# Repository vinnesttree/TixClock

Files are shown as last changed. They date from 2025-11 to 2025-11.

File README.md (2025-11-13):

# **TixClock**

The Tix Clock was originally sold in 2006 by ThinkGeek. Unfortunately, these are no longer sold. This project hopes to try to recreate this iconic clock in a miniature format.

# **TODO**
There are still things to do with this project which includes

 - Battery Management is not working
 - Encloser is not designed or tested

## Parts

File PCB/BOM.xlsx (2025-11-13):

Id | Designator | Footprint | Quantity | Designation | Supplier and ref | Column1 | _1
1 | R23,R8,R10 | R_0805_2012Metric | 3 | 1k
2 | U8 | SOIC-8-1EP_3.9x4.9mm_P1.27mm_EP2.41x3.81mm | 1 | TP4056-42-ESOP8
3 | U7 | Texas_RWU0007A_VQFN-7_2x2mm_P0.5mm | 1 | TPS61022
4 | U1 | QFN-56-1EP_7x7mm_P0.4mm_EP3.2x3.2mm | 1 | RP2040
5 | BT1 | BatteryHolder_Keystone_1042_1x18650 | 1 | Battery_Cell
6 | D31 | LED_0805_2012Metric | 1 | LED
7 | D27,D11,D24,D14,D13,D5,D10,D25,D18,D19,D15,D12,D9,D3,D6,D28,D7,D20,D2,D4,D23,D22,D17,D16,D8,D21,D26 | LED_WS2812B_PLCC4_5.0x5.0mm_P3.2mm | 27 | WS2812B
8 | U4 | SOT-23-5 | 1 | SN74LV1T34DBV
9 | R1,R2 | R_0805_2012Metric | 2 | 5.1k
10 | R3,R4 | R_0805_2012Metric | 2 | 27
11 | C9,C4,C3,C11,C2,C5 | C_0805_2012Metric | 6 | 10uF
12 | R14 | R_0805_2012Metric | 1 | 100k
13 | R21,R20 | R_0805_2012Metric | 2 | 4.7k
14 | U3 | SOIC-8_5.3x5.3mm_P1.27mm | 1 | W25Q32JVSS
15 | SW2,SW4,SW1,SW3 | SW_SPST_CK_RS282G05A3 | 4 | SW_SPST
16 | D1,D30,D29 | D_SMA | 3 | D_Schottky_Small
17 | R18,R19,R16,R17,R7,R15,R6 | R_0805_2012Metric | 7 | 10k
18 | R13 | R_0805_2012Metric | 1 | 732k
19 | U2 | SOT-223-3_TabPin2 | 1 | AMS1117-3.3
20 | C1,C10 | C_0805_2012Metric | 2 | 100nF
21 | R11 | R_0805_2012Metric | 1 | 1.2k
22 | R5,R9 | R_0805_2012Metric | 2 | 100
23 | Q1 | TSOP-6_1.65x3.05mm_P0.95mm | 1 | PMN48XP
24 | J2 | PinSocket_1x03_P2.54mm_Vertical | 1 | Conn_01x03
25 | C6,C7 | C_0805_2012Metric | 2 | 15pF
26 | R12 | R_0805_2012Metric | 1 | 0.4
27 | Y1 | Crystal_SMD_SeikoEpson_FA238-4Pin_3.2x2.5mm | 1 | 12MHz
28 | R22 | R_0805_2012Metric | 1 | 1M
29 | L1 | L_0805_2012Metric | 1 | 1uH
30 | U6 | SOT95P285X140-6N | 1 | 8205A
31 | BT2 | BatteryHolder_Keystone_3034_1x20mm | 1 | Battery_Cell
32 | U5 | SOT-23-6 | 1 | DW01A
33 | C8 | C_0805_2012Metric | 1 | 0.1uF
34 | U9 | SOIC-8_3.9x4.9mm_P1.27mm | 1 | PCF8523T
35 | J1 | USB_C_Receptacle_HRO_TYPE-C-31-M-12 | 1 | USB_C_Receptacle_USB2.0_16P

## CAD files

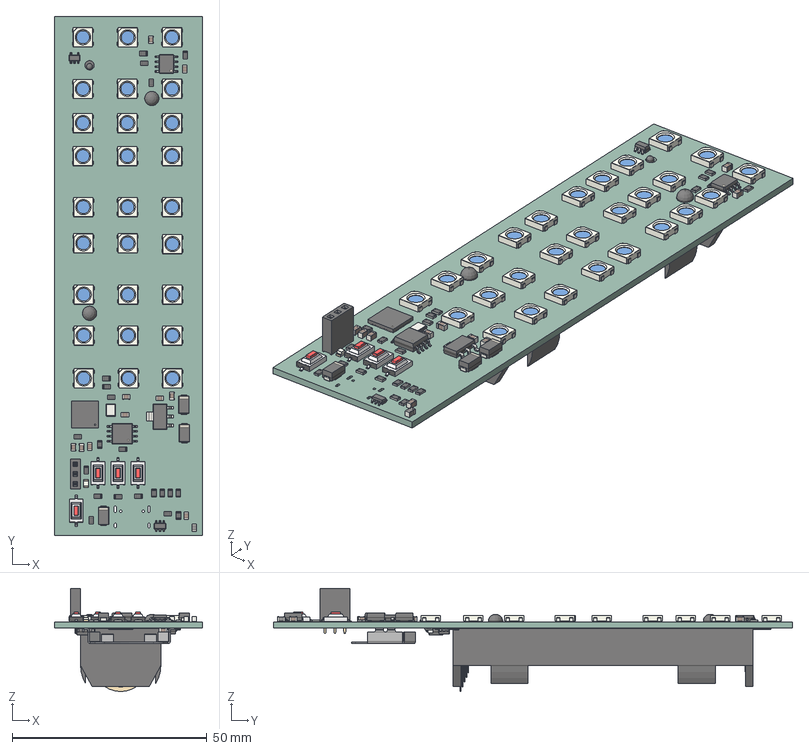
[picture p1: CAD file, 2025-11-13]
PCB/PCBProject.step
38.1 x 133.4 x 26.5 mm
LED_WS2812B_PLCC4_5.0x5.0mm_P3.2mm x 27
SOT-23-5
R_0805_2012Metric x 23
SOIC-8-1EP_3.9x4.9mm_P1.27mm_EP2.41x3.81mm
C_0805_2012Metric x 11
SOIC-8_5.3x5.3mm_P1.27mm
SW_SPST_CK_RS282G05A3 x 4
D_SMA x 3
SOT-223
LED_0805_2012Metric
TSOP-6_1.65x3.05mm_P0.95mm
QFN-56-1EP_7x7mm_P0.4mm_EP3.2x3.2mm
PinSocket_1x03_P2.54mm_Vertical
Crystal_SMD_SeikoEpson_FA238-4Pin_3.2x2.5mm
L_0805_2012Metric
BatteryHolder_Keystone_1042_1x18650
BatteryHolder_Keystone_3034_1x20mm
SOT-23-6
SOIC-8_3.9x4.9mm_P1.27mm
PCBProject_PCB

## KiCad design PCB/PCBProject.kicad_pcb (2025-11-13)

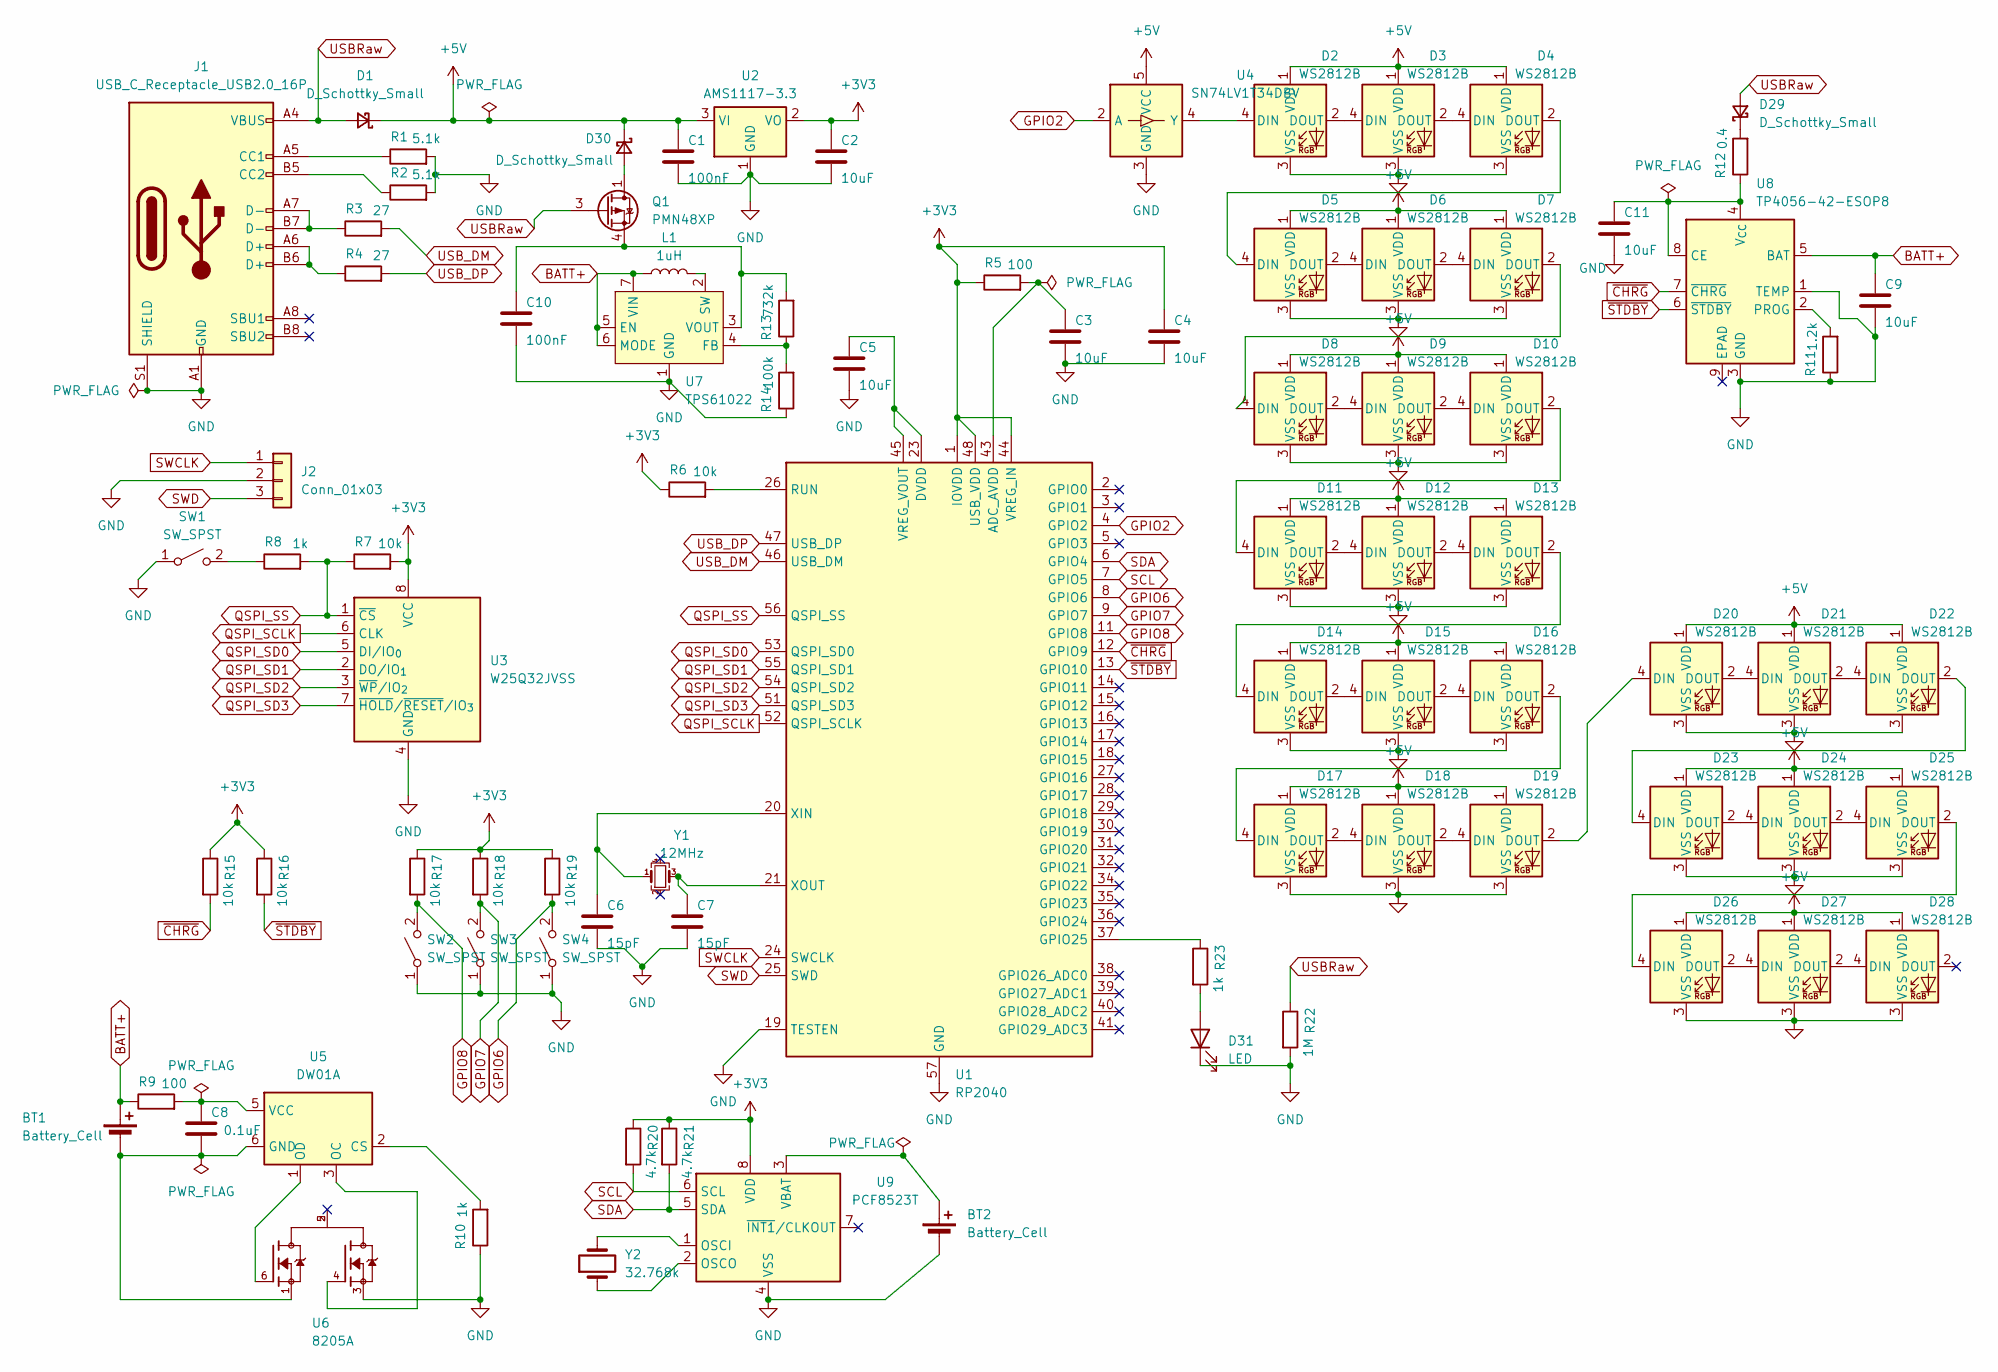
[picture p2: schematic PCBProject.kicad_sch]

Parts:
BT1: Battery_Cell; BatteryHolder_Keystone_1042_1x18650
BT2: Battery_Cell; BatteryHolder_Keystone_3034_1x20mm
C1, C10: 100nF; C_0805_2012Metric
C2, C3, C4, C5, C9, C11: 10uF; C_0805_2012Metric
C6, C7: 15pF; C_0805_2012Metric
C8: 0.1uF; C_0805_2012Metric
D1, D29, D30: D_Schottky_Small; D_SMA
D2, D3, D4, D5, D6, D7, D8, D9, D10, D11, D12, D13, D14, D15, D16, D17, D18, D19, D20, D21, D22, D23, D24, D25, D26, D27, D28: WS2812B; LED_WS2812B_PLCC4_5.0x5.0mm_P3.2mm
D31: LED; LED_0805_2012Metric
J1: USB_C_Receptacle_USB2.0_16P; USB_C_Receptacle_HRO_TYPE-C-31-M-12
J2: Conn_01x03; PinSocket_1x03_P2.54mm_Vertical
L1: 1uH; L_0805_2012Metric
Q1: PMN48XP; TSOP-6_1.65x3.05mm_P0.95mm
R1, R2: 5.1k; R_0805_2012Metric
R3, R4: 27; R_0805_2012Metric
R5, R9: 100; R_0805_2012Metric
R6, R7, R15, R16, R17, R18, R19: 10k; R_0805_2012Metric
R8, R10, R23: 1k; R_0805_2012Metric
R11: 1.2k; R_0805_2012Metric
R12: 0.4; R_0805_2012Metric
R13: 732k; R_0805_2012Metric
R14: 100k; R_0805_2012Metric
R20, R21: 4.7k; R_0805_2012Metric
R22: 1M; R_0805_2012Metric
SW1, SW2, SW3, SW4: SW_SPST; SW_SPST_CK_RS282G05A3
U1: RP2040; QFN-56-1EP_7x7mm_P0.4mm_EP3.2x3.2mm
U2: AMS1117-3.3; SOT-223-3_TabPin2
U3: W25Q32JVSS; SOIC-8_5.3x5.3mm_P1.27mm
U4: SN74LV1T34DBV; SOT-23-5
U5: DW01A; SOT-23-6
U6: 8205A; SOT95P285X140-6N; PARTREV NA
U7: TPS61022; Texas_RWU0007A_VQFN-7_2x2mm_P0.5mm
U8: TP4056-42-ESOP8; SOIC-8-1EP_3.9x4.9mm_P1.27mm_EP2.41x3.81mm
U9: PCF8523T; SOIC-8_3.9x4.9mm_P1.27mm
Y1: 12MHz; Crystal_SMD_SeikoEpson_FA238-4Pin_3.2x2.5mm
Y2: 32.768k

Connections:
+3V3: C2.1, C4.1, R5.1, R6.1, R7.2, R15.1, R16.1, R17.1, R18.1, R19.1, R20.1, R21.1, U1.1 (IOVDD), U1.10 (IOVDD), U1.22 (IOVDD), U1.33 (IOVDD), U1.42 (IOVDD), U1.44 (VREG_IN), U1.48 (USB_VDD), U1.49 (IOVDD), U2.2 (VO), U3.8 (VCC), U9.8 (VDD)
+5V: C1.1, D1.1 (K), D2.1 (VDD), D3.1 (VDD), D4.1 (VDD), D5.1 (VDD), D6.1 (VDD), D7.1 (VDD), D8.1 (VDD), D9.1 (VDD), D10.1 (VDD), D11.1 (VDD), D12.1 (VDD), D13.1 (VDD), D14.1 (VDD), D15.1 (VDD), D16.1 (VDD), D17.1 (VDD), D18.1 (VDD), D19.1 (VDD), D20.1 (VDD), D21.1 (VDD), D22.1 (VDD), D23.1 (VDD), D24.1 (VDD), D25.1 (VDD), D26.1 (VDD), D27.1 (VDD), D28.1 (VDD), D30.1 (K), U2.3 (VI), U4.5 (VCC)
BATT+: BT1.1 (+), C9.1, L1.1, R9.1, U7.5 (EN), U7.6 (MODE), U7.7 (VIN), U8.5 (BAT)
GND: BT2.2 (-), C1.2, C2.2, C3.2, C4.2, C5.2, C6.2, C7.2, C9.2, C10.2, C11.2, D2.3 (VSS), D3.3 (VSS), D4.3 (VSS), D5.3 (VSS), D6.3 (VSS), D7.3 (VSS), D8.3 (VSS), D9.3 (VSS), D10.3 (VSS), D11.3 (VSS), D12.3 (VSS), D13.3 (VSS), D14.3 (VSS), D15.3 (VSS), D16.3 (VSS), D17.3 (VSS), D18.3 (VSS), D19.3 (VSS), D20.3 (VSS), D21.3 (VSS), D22.3 (VSS), D23.3 (VSS), D24.3 (VSS), D25.3 (VSS), D26.3 (VSS), D27.3 (VSS), D28.3 (VSS), D31.1 (K), J1.A1 (GND), J1.A12 (GND), J1.B1 (GND), J1.B12 (GND), J1.S1 (SHIELD), J2.2, R1.2, R2.2, R10.1, R11.1, R14.1, R22.2, SW1.1 (A), SW2.1 (A), SW3.1 (A), SW4.1 (A), U1.19 (TESTEN), U1.57 (GND), U2.1 (GND), U3.4 (GND), U4.3 (GND), U6.3, U7.1 (GND), U8.1 (TEMP), U8.3 (GND), U9.4 (VSS)
GPIO2: U1.4 (GPIO2), U4.2 (A)
GPIO6: R19.2, SW4.2 (B), U1.8 (GPIO6)
GPIO7: R18.2, SW3.2 (B), U1.9 (GPIO7)
GPIO8: R17.2, SW2.2 (B), U1.11 (GPIO8)
unnamed: BT1.2 (-), C8.2, U5.6 (GND), U6.1
unnamed: BT2.1 (+), U9.3 (VBAT)
unnamed: D2.4 (DIN), U4.4 (Y)
unnamed: D2.2 (DOUT), D3.4 (DIN)
unnamed: D3.2 (DOUT), D4.4 (DIN)
unnamed: D4.2 (DOUT), D5.4 (DIN)
unnamed: D5.2 (DOUT), D6.4 (DIN)
unnamed: D6.2 (DOUT), D7.4 (DIN)
unnamed: D7.2 (DOUT), D8.4 (DIN)
unnamed: D8.2 (DOUT), D9.4 (DIN)
unnamed: D9.2 (DOUT), D10.4 (DIN)
unnamed: D10.2 (DOUT), D11.4 (DIN)
unnamed: D11.2 (DOUT), D12.4 (DIN)
unnamed: D12.2 (DOUT), D13.4 (DIN)
unnamed: D13.2 (DOUT), D14.4 (DIN)
unnamed: D14.2 (DOUT), D15.4 (DIN)
unnamed: D15.2 (DOUT), D16.4 (DIN)
unnamed: D16.2 (DOUT), D17.4 (DIN)
unnamed: D17.2 (DOUT), D18.4 (DIN)
unnamed: D18.2 (DOUT), D19.4 (DIN)
unnamed: D19.2 (DOUT), D20.4 (DIN)
unnamed: D20.2 (DOUT), D21.4 (DIN)
unnamed: D21.2 (DOUT), D22.4 (DIN)
unnamed: D22.2 (DOUT), D23.4 (DIN)
unnamed: D23.2 (DOUT), D24.4 (DIN)
unnamed: D24.2 (DOUT), D25.4 (DIN)
unnamed: D25.2 (DOUT), D26.4 (DIN)
unnamed: D26.2 (DOUT), D27.4 (DIN)
unnamed: D27.2 (DOUT), D28.4 (DIN)
unnamed: D29.1 (K), R12.2
unnamed: D30.2 (A), Q1.1 (D), Q1.2 (D), Q1.5 (D), Q1.6 (D)
unnamed: D31.2 (A), R23.2
unnamed: J1.A5 (CC1), R1.1
unnamed: J1.B5 (CC2), R2.1
unnamed: J1.A6 (D+), J1.B6 (D+), R4.1
unnamed: J1.A7 (D-), J1.B7 (D-), R3.1
unnamed: C10.1, Q1.4 (S), R13.2, U7.3 (VOUT)
unnamed: R8.1, SW1.2 (B)
unnamed: C3.1, R5.2, U1.43 (ADC_AVDD)
unnamed: R23.1, U1.37 (GPIO25)
unnamed: R6.2, U1.26 (RUN)
unnamed: C5.1, U1.23 (DVDD), U1.45 (VREG_VOUT), U1.50 (DVDD)
unnamed: C6.1, U1.20 (XIN), Y1.1
unnamed: C7.1, U1.21 (XOUT), Y1.3
unnamed: R10.2, U5.2 (CS)
unnamed: U5.3 (OC), U6.4
unnamed: U5.1 (OD), U6.6
unnamed: C8.1, R9.2, U5.5 (VCC)
unnamed: R13.1, R14.2, U7.4 (FB)
unnamed: L1.2, U7.2 (SW)
unnamed: C11.1, R12.1, U8.4 (V_{CC}), U8.8 (CE)
unnamed: R11.2, U8.2 (PROG)
unnamed: U9.2 (OSCO), Y2.1
unnamed: U9.1 (OSCI), Y2.2
QSPI_SCLK: U1.52 (QSPI_SCLK), U3.6 (CLK)
QSPI_SD0: U1.53 (QSPI_SD0), U3.5 (DI/IO_{0})
QSPI_SD1: U1.55 (QSPI_SD1), U3.2 (DO/IO_{1})
QSPI_SD2: U1.54 (QSPI_SD2), U3.3 (~WP/IO_{2})
QSPI_SD3: U1.51 (QSPI_SD3), U3.7 (~HOLD/~RESET/IO_{3})
QSPI_SS: R7.1, R8.2, U1.56 (QSPI_SS), U3.1 (~CS)
SCL: R20.2, U1.7 (GPIO5), U9.6 (SCL)
SDA: R21.2, U1.6 (GPIO4), U9.5 (SDA)
SWCLK: J2.1, U1.24 (SWCLK)
SWD: J2.3, U1.25 (SWD)
USBRaw: D1.2 (A), D29.2 (A), J1.A4 (VBUS), J1.A9 (VBUS), J1.B4 (VBUS), J1.B9 (VBUS), Q1.3 (G), R22.1
USB_DM: R3.2, U1.46 (USB_DM)
USB_DP: R4.2, U1.47 (USB_DP)
~CHRG: R15.2, U1.12 (GPIO9), U8.7 (~CHRG)
~STDBY: R16.2, U1.13 (GPIO10), U8.6 (~STDBY)

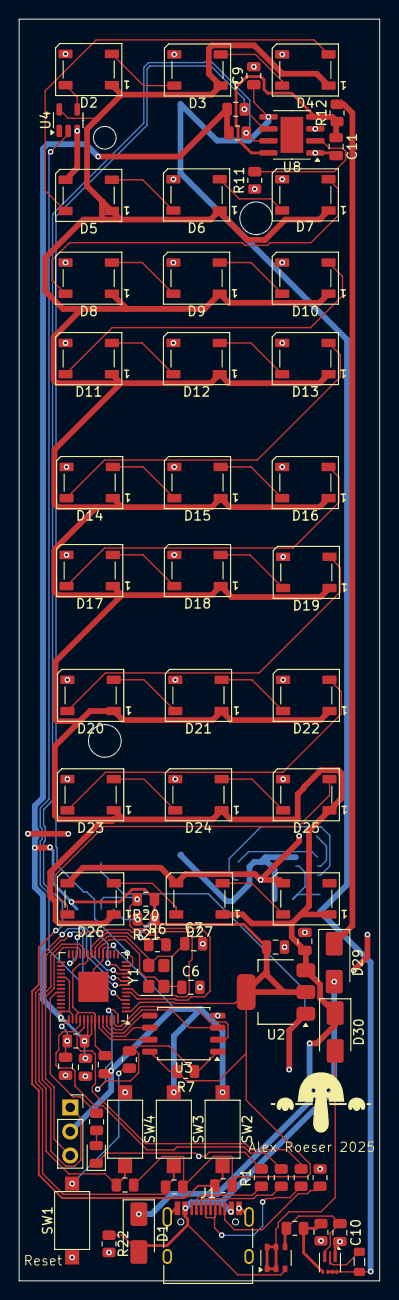
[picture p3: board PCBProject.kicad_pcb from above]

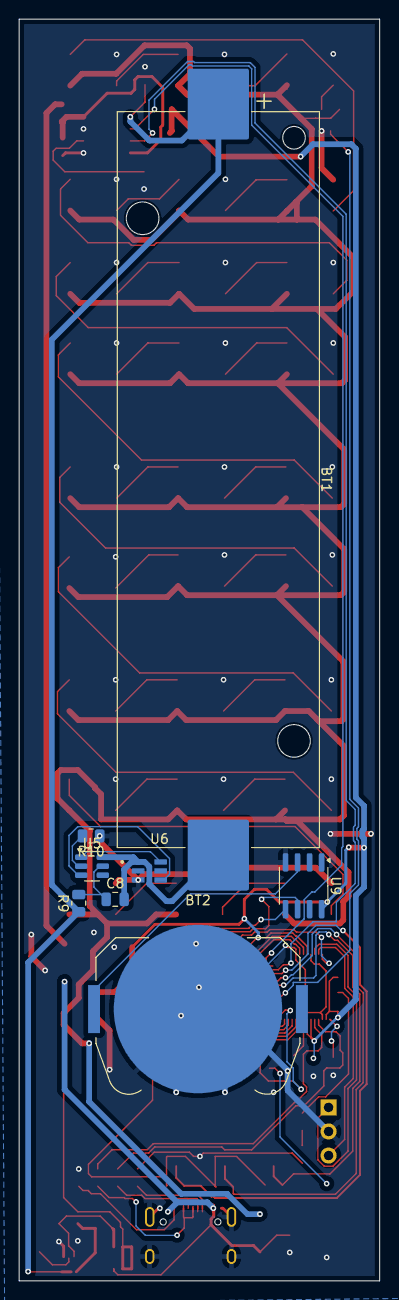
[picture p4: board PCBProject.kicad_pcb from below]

Board: 2 copper layers, 38.1 x 133.4 mm, 85 parts (8 on the bottom side), 75 nets.

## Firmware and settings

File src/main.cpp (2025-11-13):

#include <FastLED.h>
#include <Wire.h>
#include <cstdint>
#include <I2C_RTC.h>
#include <arduino.h>
#include "hardware/structs/sio.h"
#include "hardware/structs/iobank0.h"
#include "hardware/regs/addressmap.h"
#include "hardware/timer.h"

//Definitions
#define LED_PIN 2 //WS2812B pin
#define NUM_LEDS 27
#define SDA_PIN 4
#define SCL_PIN 5
#define Button1_PIN 6 //Set pin
#define Button2_PIN 7 //Minute pin
#define Button3_PIN 8 //Hour pin
#define Charge_PIN 9
#define Standby_PIN 10
#define Debug_PIN 25 //Debug LED pin

#define Clock_Address 0xD0

//Defines for compile time clock setting
#define CHAR_TO_INT(c) ((c) - '0')

#define HOUR   (CHAR_TO_INT(__TIME__[0]) * 10 + CHAR_TO_INT(__TIME__[1]))
#define MINUTE (CHAR_TO_INT(__TIME__[3]) * 10 + CHAR_TO_INT(__TIME__[4]))
#define SECOND (CHAR_TO_INT(__TIME__[6]) * 10 + CHAR_TO_INT(__TIME__[7]))

//Global Variables
static PCF8523 RTC;
CRGB leds[NUM_LEDS];
uint8_t hour = 0;
uint8_t minute = 0;
uint32_t offset = 0;
uint32_t blinkTime = 0;
uint8_t setButtonPrev = 0;

void ReadClockData(uint8_t *hours, uint8_t *minutes){
  *hours = RTC.getHours();
  *minutes = RTC.getMinutes();
  /*
  Serial.print(*hours);
  Serial.print(":");
  Serial.println(*minutes);
  */
}

void SetClockData(uint8_t hour, uint8_t minute){

}

uint16_t generate_pattern(uint32_t rand_val, uint8_t on_bits, uint8_t total_bits) {
    if (total_bits > 16) total_bits = 16;
    if (on_bits > total_bits) on_bits = total_bits;

    uint16_t pattern = 0;
    uint8_t count = 0;

    // Fill the rightmost 'total_bits' using bits from rand_val
    for (uint8_t i = 0; i < total_bits && count < on_bits; i++) {
        if ((rand_val >> i) & 1U) {
            pattern |= (1U << i);
            count++;
        }
    }

    // If we didn’t get enough ON bits, fill remaining from LSB upwards
    for (uint8_t i = 0; i < total_bits && count < on_bits; i++) {
        if (!(pattern & (1U << i))) {
            pattern |= (1U << i);
            count++;
        }
    }

    // Mask to ensure only 'total_bits' are used and pattern is right-aligned
    pattern &= (1U << total_bits) - 1;

    return pattern;
}


void SetLEDs(uint8_t hours, uint8_t minutes){
  //Clear all LEDs
  FastLED.clear();

  uint32_t random_value = get_rand_32();

  //Set hours LEDs
  int hour10 = hours / 10;
  int hour1 = hours % 10;
  uint16_t hour10_pattern = generate_pattern(random_value, hour10, 3);
  uint16_t hour1_pattern = generate_pattern(random_value >> 8, hour1, 9);
  for(uint8_t i=0; i<3; i++){
    if(hour10_pattern & (1 << i)){
      leds[i] = CRGB::Red;
    } else {
      leds[i] = CRGB::Black;
    }
  }
  for(uint8_t i=0; i<9; i++){
    if(hour1_pattern & (1 << i)){
      leds[i+3] = CRGB::Green;
    } else {
      leds[i+3] = CRGB::Black;
    }
  }

 //Set minutes LEDs
  int minute10 = minutes / 10;
  int minute1 = minutes % 10;
  uint16_t minute10_pattern = generate_pattern(random_value >> 16, minute10, 6);
  uint16_t minute1_pattern = generate_pattern(random_value >> 24, minute1, 9);
  for(uint8_t i=0; i<6; i++){
    if(minute10_pattern & (1 << i)){
      leds[i+12] = CRGB::Blue;
    } else {
      leds[i+12] = CRGB::Black;
    }
  }
  for(uint8_t i=0; i<9; i++){
    if(minute1_pattern & (1 << i)){
      leds[i+18] = CRGB::Yellow;
    } else {
      leds[i+18] = CRGB::Black;
    }
  }

  FastLED.show();
}

void SetLEDsNRAND(uint8_t hours, uint8_t minutes){ //Set LEDs without randomness for easier setting
  //Clear all LEDs
  FastLED.clear();


  //Set hours LEDs
  int hour10 = hours / 10;
  int hour1 = hours % 10;
  for(uint8_t i=0; i<hour10; i++){
    leds[i] = CRGB::Red;
  }
  for(uint8_t i=0; i<hour1; i++){
    leds[i+3] = CRGB::Green;
  }

 //Set minutes LEDs
  int minute10 = minutes / 10;
  int minute1 = minutes % 10;
  for(uint8_t i=0; i<minute10; i++){
    leds[i+12] = CRGB::Blue;
  }
  for(uint8_t i=0; i<minute1; i++){
    leds[i+18] = CRGB::Yellow;
  }

  FastLED.show();

}

void setup(){
  //Initialize FastLED and RTC Communication
  FastLED.addLeds<NEOPIXEL, LED_PIN>(leds, NUM_LEDS);
  FastLED.setBrightness(25);

  //Serial.begin(115200);
  //RTC.begin();

  

  pinMode(Button1_PIN, INPUT);
  pinMode(Button2_PIN, INPUT);
  pinMode(Button3_PIN, INPUT);
  pinMode(Charge_PIN, INPUT);
  pinMode(Standby_PIN, INPUT);

  pinMode(Debug_PIN, OUTPUT);


  //RTC.setHourMode(CLOCK_H24);
  hour = HOUR;
  minute = MINUTE;
  offset = (60 - SECOND) * 1000; //offset time in ms (time past top of the minute)
  //offset = 60 * 1000 - (RTC.getSeconds() * 1000); //calculate offset to next minute

  //ReadClockData(&hour, &minute);

  SetLEDs(hour, minute);

}

void loop(){
  uint32_t currentTime = millis();

  // Poll if a minute has passed
  if(currentTime >= offset){
    offset += 60 * 1000; //set next offset
    minute++;
    if(minute >= 60){
      minute = 0;
      hour++;
      if(hour >= 24){
        hour = 0;
      }
    }
    SetLEDs(hour, minute);
    //minute++;
  }

  if(currentTime >= blinkTime){
    blinkTime += 500; //set next blink
    digitalWrite(Debug_PIN, !digitalRead(Debug_PIN));
  }

  while(digitalRead(Button1_PIN) == LOW){ //Holding button 1 acts as a set
    delay(20); //debounce
    if(digitalRead(Button1_PIN) == LOW){
      SetLEDsNRAND(hour, minute);
      setButtonPrev = LOW;
      if(digitalRead(Button2_PIN) == LOW){
        delay(20); //debounce
        if(digitalRead(Button2_PIN) == LOW){
          minute++;
          if(minute >= 60){
            minute = 0;
            hour++;
            if(hour >= 24){
              hour = 0;
            }
          }
          SetLEDsNRAND(hour, minute);
          while(digitalRead(Button2_PIN) == LOW); //wait for release
        }
      }
      if(digitalRead(Button3_PIN) == LOW){
        delay(20); //debounce
        if(digitalRead(Button3_PIN) == LOW){
          hour++;
          if(hour >= 24){
            hour = 0;
          }
          SetLEDsNRAND(hour, minute);
          while(digitalRead(Button3_PIN) == LOW); //wait for release
        }
      }
    }
  }

  if(setButtonPrev == LOW){ //Re-display time with the random effect only when button is released
    //SetLEDs(hour, minute);
    //SetClockData(hour, minute); //set RTC after setting time
    offset = currentTime; //reset offset (seconds past top of minute)
    minute--; //account for trigger to not increment time
    setButtonPrev = HIGH;
  }

}
